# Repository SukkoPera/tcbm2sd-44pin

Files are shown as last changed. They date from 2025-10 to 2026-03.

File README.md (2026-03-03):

# TCBM2SD 44-pin
TCBM2SD is a CBM 1551 paddle replacement and/or mass storage device using an SD card interfacing with the Commodore C16/116/Plus4 simulating a TCBM bus 1551 disk drive.

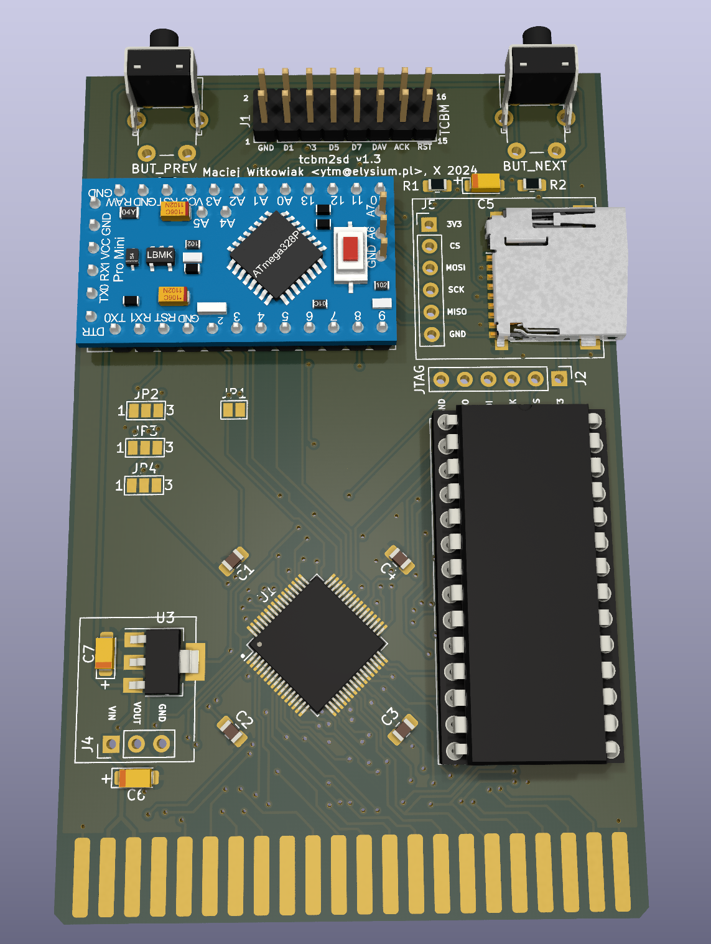
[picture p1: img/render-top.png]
Board


## Summary
This is a 44-pin variant of [the original project by Maciej 'YTM/Elysium' Witkowiak](https://github.com/ytmytm/plus4-tcbm2sd).

This version is still aimed at the C16/C116/Plus4 and it **requires** the usage of a [Plus4MultiExpander](https://github.com/SukkoPera/Plus4MultiExpander) or something similar. It is NOT compatible with the C64/C128.

Isn't Open Hardware great?

## Usage
This variant of the board requires the FPGA to be flashed with the JED file from this project. The corresponding sources are available in the [hdl](hdl/) directory.

Apart from that, please refer to [the original project](https://github.com/ytmytm/plus4-tcbm2sd) for documentation, instructions, etc.

## Releases
If you want to get this board produced, you are recommended to get [the latest release](https://github.com/SukkoPera/tcbm2sd-44pin/releases) rather than the current git version, as the latter might be under development and is not guaranteed to be working.

Every release is accompanied by its Bill Of Materials (BOM) file and any relevant notes about it, which you are recommended to read carefully.

## License
TCBM2SD is licensed under the [Creative Commons Attribution-ShareAlike 4.0 International License](https://creativecommons.org/licenses/by-sa/4.0/).

This documentation is distributed *as is* and WITHOUT ANY EXPRESS OR IMPLIED WARRANTIES whatsoever with respect to its functionality, operability or use, including, without limitation, any implied warranties OF MERCHANTABILITY, SATISFACTORY QUALITY, FITNESS FOR A PARTICULAR PURPOSE or infringement. We expressly disclaim any liability whatsoever for any direct, indirect, consequential, incidental or special damages, including, without limitation, lost revenues, lost profits, losses resulting from business interruption or loss of data, regardless of the form of action or legal theory under which the liability may be asserted, even if advised of the possibility or likelihood of such damages.

## Thanks
- Thanks to Maciej for his amazing work and support.
- 3D model of Arduino Pro Micro by [Toby](https://grabcad.com/library/arduino-pro-mini-5v-16mhz-1).

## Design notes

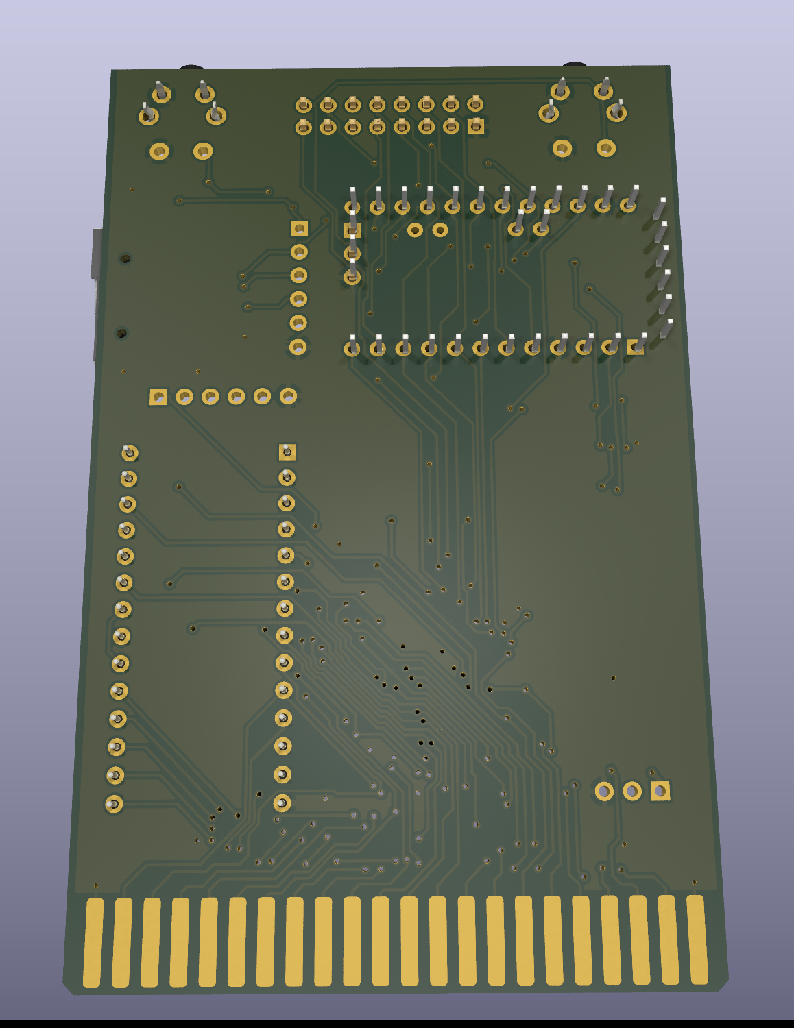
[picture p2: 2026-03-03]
img/render-bottom.png

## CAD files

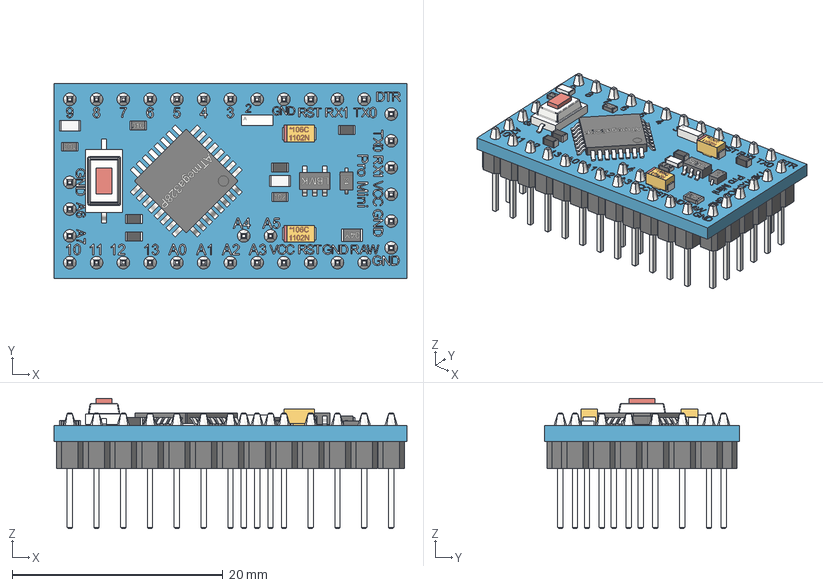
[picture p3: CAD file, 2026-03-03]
tcbm2sd/3dModels/Arduino_Pro_Mini_5V_16MHz.step
33.5 x 18.5 x 12.4 mm
board
led
102_smd_resistor
reset_button
01C_smd_resistor
smd_capacitor
smd_capacitor (1)
ATmega328P
16MHz Resonator v1
led (1)
102_smd_resistor (1)
smd_capacitor (2)
106C_smd_tantalum_capacitor
106C_smd_tantalum_capacitor (2)
5V_regulator
s4_smd_diode
smd_capacitor (3)
04Y_smd_resistor
Pin_Header x 15
Pin_Header (1) x 12
Pin_Header (1) (1) x 6
Pin_Header (2)
Pin_Header (2) (1)
solder x 15
solder (1) x 6
solder (2) x 12
solder (3)
solder (4)

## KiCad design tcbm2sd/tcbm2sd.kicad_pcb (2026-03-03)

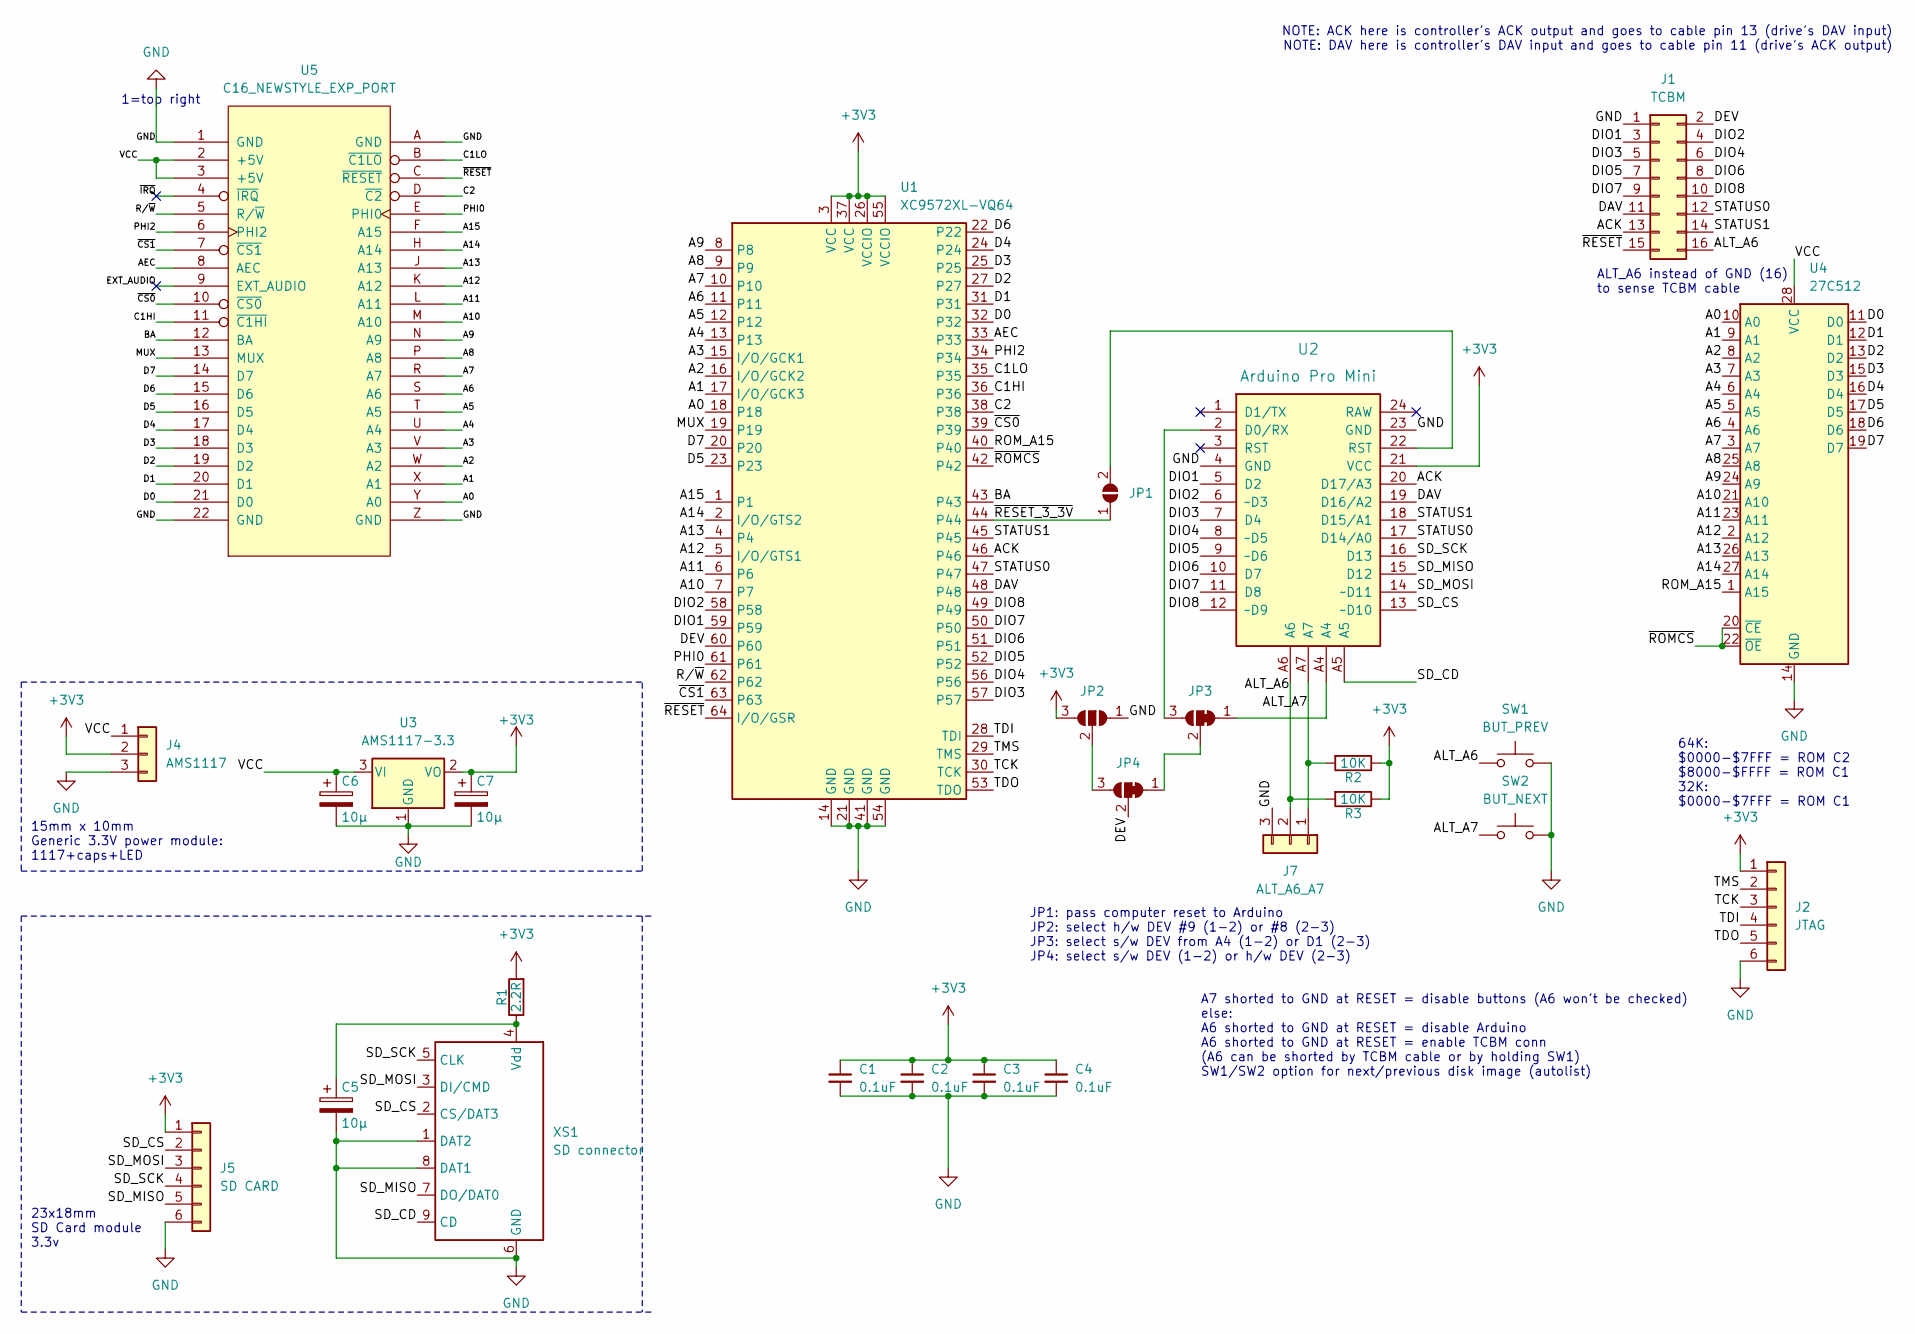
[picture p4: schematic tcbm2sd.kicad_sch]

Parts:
C1, C2, C3, C4: 0.1uF; C_0805_2012Metric_Pad1.18x1.45mm_HandSolder; JLCPCB Part # C49678
C5, C6, C7: 10µ; CP_EIA-3216-12_Kemet-S_Pad1.58x1.35mm_HandSolder; JLCPCB Part # C1969735
J1: TCBM; PinHeader_2x08_P2.54mm_Vertical
J2: JTAG; PinHeader_1x06_P2.54mm_Vertical
J4: AMS1117; PinHeader_1x03_P2.54mm_Vertical
J5: SD CARD; PinHeader_1x06_P2.54mm_Vertical
J7: ALT_A6_A7; PinHeader_1x03_P2.54mm_Vertical
JP1: SolderJumper_2_Open; SolderJumper-2_P1.3mm_Open_Pad1.0x1.5mm
JP2: SolderJumper_3_Open; SolderJumper-3_P1.3mm_Open_Pad1.0x1.5mm_NumberLabels
JP3, JP4: SolderJumper_3_Bridged12; SolderJumper-3_P1.3mm_Bridged12_Pad1.0x1.5mm_NumberLabels
R1: 2.2R; R_0805_2012Metric_Pad1.20x1.40mm_HandSolder; JLCPCB Part # C17521
R2, R3: 10K; R_0805_2012Metric_Pad1.20x1.40mm_HandSolder; JLCPCB Part # C17414
SW1: BUT_PREV; SW_PUSH_6mm_OR_SW_Tactile_SPST_Angled_PTS645Vx58-2LFS
SW2: BUT_NEXT; SW_PUSH_6mm_OR_SW_Tactile_SPST_Angled_PTS645Vx58-2LFS
U1: XC9572XL-VQ64; TQFP-64_10x10mm_P0.5mm; JLCPCB Part # C90569
U2: Arduino Pro Mini; Arduino_Pro_Mini
U3: AMS1117-3.3; SOT-223-3_TabPin2; JLCPCB Part # C6186
U4: 27C512; DIP-28_W15.24mm_Socket
U5: C16_NEWSTYLE_EXP_PORT; EdgeConn-44pin
XS1: SD connector; Conn_uSDcard; JLCPCB Part # C7529389

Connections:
+3V3: C1.1, C2.1, C3.1, C4.1, C7.1, J2.1, J4.2, J5.1, JP2.3 (B), R1.2, R2.1, R3.1, U1.3 (VCC), U1.26 (VCCIO), U1.37 (VCC), U1.55 (VCCIO), U2.21 (VCC), U3.2 (VO)
/A0: U1.18, U4.10 (A0), U5.Y (A0)
/A1: U1.17 (I/O/GCK3), U4.9 (A1), U5.X (A1)
/A2: U1.16 (I/O/GCK2), U4.8 (A2), U5.W (A2)
/A3: U1.15 (I/O/GCK1), U4.7 (A3), U5.V (A3)
/A4: U1.13, U4.6 (A4), U5.U (A4)
/A5: U1.12, U4.5 (A5), U5.T (A5)
/A6: U1.11, U4.4 (A6), U5.S (A6)
/A7: U1.10, U4.3 (A7), U5.R (A7)
/A8: U1.9, U4.25 (A8), U5.P (A8)
/A9: U1.8, U4.24 (A9), U5.N (A9)
/A10: U1.7, U4.21 (A10), U5.M (A10)
/A11: U1.6, U4.23 (A11), U5.L (A11)
/A12: U1.5 (I/O/GTS1), U4.2 (A12), U5.K (A12)
/A13: U1.4, U4.26 (A13), U5.J (A13)
/A14: U1.2 (I/O/GTS2), U4.27 (A14), U5.H (A14)
/A15: U1.1, U5.F (A15)
/ACK: J1.13, U1.46, U2.20 (D17/A3)
/AEC: U1.33, U5.8 (AEC)
/ALT_A6: J1.16, J7.2, R3.2, SW1.1, U2.A6
/ALT_A7: J7.1, R2.2, SW2.1, U2.A7
/BA: U1.43, U5.12 (BA)
/C1HI: U1.36, U5.11 (~C1HI)
/C1LO: U1.35, U5.B (~C1LO)
/C2: U1.38, U5.D (~C2)
/D0: U1.32, U4.11 (D0), U5.21 (D0)
/D1: U1.31, U4.12 (D1), U5.20 (D1)
/D2: U1.27, U4.13 (D2), U5.19 (D2)
/D3: U1.25, U4.15 (D3), U5.18 (D3)
/D4: U1.24, U4.16 (D4), U5.17 (D4)
/D5: U1.23, U4.17 (D5), U5.16 (D5)
/D6: U1.22, U4.18 (D6), U5.15 (D6)
/D7: U1.20, U4.19 (D7), U5.14 (D7)
/DAV: J1.11, U1.48, U2.19 (D16/A2)
/DEV: J1.2, JP4.2 (C), U1.60
/DIO1: J1.3, U1.59, U2.5 (D2)
/DIO2: J1.4, U1.58, U2.6 (~D3)
/DIO3: J1.5, U1.57, U2.7 (D4)
/DIO4: J1.6, U1.56, U2.8 (~D5)
/DIO5: J1.7, U1.52, U2.9 (~D6)
/DIO6: J1.8, U1.51, U2.10 (D7)
/DIO7: J1.9, U1.50, U2.11 (D8)
/DIO8: J1.10, U1.49, U2.12 (~D9)
/EXT_AUDIO: U5.9 (EXT_AUDIO)
/MUX: U1.19, U5.13 (MUX)
/PHI0: U1.61, U5.E (PHI0)
/PHI2: U1.34, U5.6 (PHI2)
/ROM_A15: U1.40, U4.1 (A15)
/R/~W: U1.62, U5.5 (R/~W)
/SD_CD: U2.A5, XS1.9 (CD)
/SD_CS: J5.2, U2.13 (~D10), XS1.2 (CS/DAT3)
/SD_MISO: J5.5, U2.15 (D12), XS1.7 (DO/DAT0)
/SD_MOSI: J5.3, U2.14 (~D11), XS1.3 (DI/CMD)
/SD_SCK: J5.4, U2.16 (D13), XS1.5 (CLK)
/STATUS0: J1.12, U1.47, U2.17 (D14/A0)
/STATUS1: J1.14, U1.45, U2.18 (D15/A1)
/TCK: J2.3, U1.30 (TCK)
/TDI: J2.4, U1.28 (TDI)
/TDO: J2.5, U1.53 (TDO)
/TMS: J2.2, U1.29 (TMS)
/VCC: C6.1, J4.1, U3.3 (VI), U4.28 (VCC), U5.2 (+5V), U5.3 (+5V)
/~CS0: U1.39, U5.10 (~CS0)
/~CS1: U1.63, U5.7 (~CS1)
/~IRQ: U5.4 (~IRQ)
/~RESET_3_3V: JP1.1 (A), U1.44
/~RESET: J1.15, U1.64 (I/O/GSR), U5.C (~RESET)
/~ROMCS: U1.42, U4.20 (~CE), U4.22 (~OE)
GND: C1.2, C2.2, C3.2, C4.2, C5.2, C6.2, C7.2, J1.1, J2.6, J4.3, J5.6, J7.3, JP2.1 (A), SW1.2, SW2.2, U1.14 (GND), U1.21 (GND), U1.41 (GND), U1.54 (GND), U2.4 (GND), U2.23 (GND), U3.1 (GND), U4.14 (GND), U5.1 (GND), U5.22 (GND), U5.A (GND), U5.Z (GND), XS1.1 (DAT2), XS1.6 (GND), XS1.8 (DAT1)
unnamed: JP1.2 (B), U2.22 (RST)
unnamed: JP2.2 (C), JP4.3 (B)
unnamed: JP3.1 (A), U2.A4
unnamed: JP3.3 (B), U2.2 (D0/RX)
unnamed: JP3.2 (C), JP4.1 (A)
unnamed: C5.1, R1.1, XS1.4 (Vdd)

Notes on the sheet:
ALT_A6 instead of GND (16) to sense TCBM cable
15mm x 10mm Generic 3.3V power module: 1117+caps+LED
JP1: pass computer reset to Arduino JP2: select h/w DEV #9 (1-2) or #8 (2-3) JP3: select s/w DEV from A4 (1-2) or D1 (2-3) JP4: select s/w DEV (1-2) or h/w DEV (2-3)
A7 shorted to GND at RESET = disable buttons (A6 won't be checked) else: A6 shorted to GND at RESET = disable Arduino A6 shorted to GND at RESET = enable TCBM conn (A6 can be shorted by TCBM cable or by holding SW1) SW1/SW2 option for next/previous disk image (autolist)
NOTE: ACK here is controller's ACK output and goes to cable pin 13 (drive's DAV input) NOTE: DAV here is controller's DAV input and goes to cable pin 11 (drive's ACK output)
1=top right
23x18mm SD Card module 3.3v
64K: $0000-$7FFF = ROM C2 $8000-$FFFF = ROM C1 32K: $0000-$7FFF = ROM C1

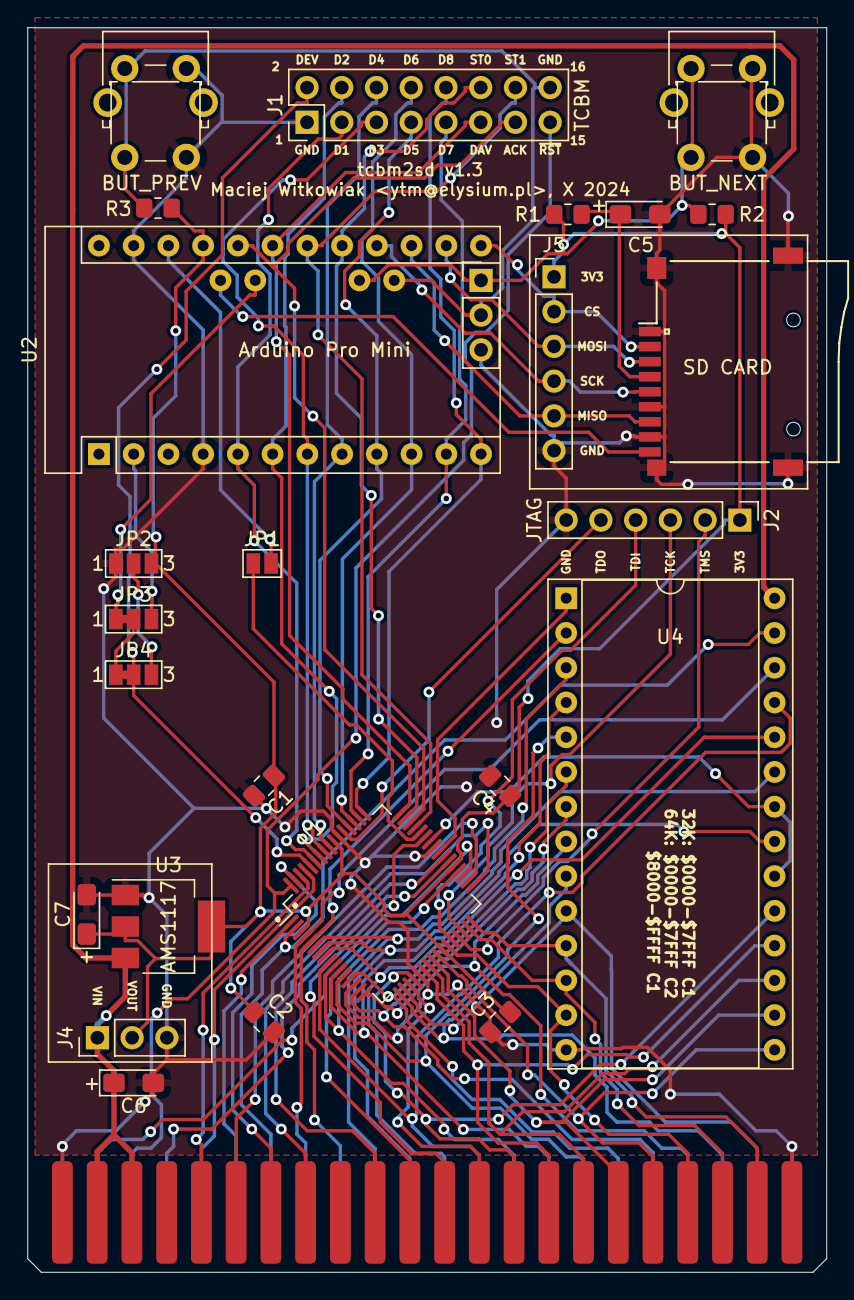
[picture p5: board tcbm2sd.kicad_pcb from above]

Board: 2 copper layers, 58.4 x 91.0 mm, 27 parts (0 on the bottom side), 72 nets.

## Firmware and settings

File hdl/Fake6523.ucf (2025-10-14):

# Fake6523A-28
NET "_reset"		LOC = "P64"  ; # /RESET exp. C
NET "_write"		LOC = "P62"  ; # R/W exp. 5
NET "data<0>"		LOC = "P32"  ; # D0 exp. 21
NET "data<1>"		LOC = "P31"  ; # D1 exp. 20
NET "data<2>"		LOC = "P27"  ; # D2 exp. 19
NET "data<3>"		LOC = "P25"  ; # D3 exp. 18
NET "data<4>"		LOC = "P24"  ; # D4 exp. 17
NET "data<5>"		LOC = "P23"  ; # D5 exp. 16
NET "data<6>"		LOC = "P22"  ; # D6 exp. 15
NET "data<7>"		LOC = "P20"  ; # D7 exp. 14
NET "port_a<0>"	LOC = "P59"  ; # DIO1, <-> wire 3
NET "port_a<1>"	LOC = "P58"  ; # DIO2, <-> wire 4
NET "port_a<2>"	LOC = "P57"  ; # DIO3, <-> wire 5
NET "port_a<3>"	LOC = "P56"  ; # DIO4, <-> wire 6
NET "port_a<4>"	LOC = "P52"  ; # DIO5, <-> wire 7
NET "port_a<5>"	LOC = "P51"  ; # DIO6, <-> wire 8
NET "port_a<6>"	LOC = "P50"  ; # DIO7, <-> wire 9
NET "port_a<7>"	LOC = "P49"  ; # DIO8, <-> wire 10
NET "port_b<0>"	LOC = "P47"  ; # STATUS0, <-, wire 12
NET "port_b<1>"	LOC = "P45"  ; # STATUS1, <-, wire 14
NET "port_c<6>"	LOC = "P46"  ; # ACK, ->, wire 13 (controller's ACK out, drive's DAV in)
NET "port_c<7>"	LOC = "P48"  ; # DAV, <-, wire 11 (controller's DAV in,  drive's ACK out)
NET "rs<0>"			LOC = "P18"  ; # A0 exp. Y
NET "rs<1>"			LOC = "P17"  ; # A1 exp. X
NET "rs<2>"			LOC = "P16"  ; # A2 exp. W

# other inputs
NET "phi2"			LOC = "P34"  ;	# Phi2 exp. 24
NET "aec" 			LOC = "P33"  ; # AEC exp. 22
NET "ba"				LOC = "P43"  ; # BA exp. 13

# ROM control
NET "c1lo"			LOC = "P35"	 ; # J3-1			<- C1LO exp. B
NET "c1hi"			LOC = "P36"  ; # J3-2			<- C1HI exp. 6
NET "c2"				LOC = "P38"  ; # J3-3			<- C2  exp. D (combined C2LO/C2HI)
NET "cs0"			LOC = "P39"  ; # J3-4			<- CS0 exp. 10
NET "rom_a15"		LOC = "P40"  ; # J3-5			-> ROM A15 1
NET "rom_cs"		LOC = "P42"  ; # /CAS			-> ROM /CE/OE 20+22

# PLA inputs
NET "pla_i<1>"		LOC = "P6"	 ; # PLA I1 (8)   <- A11 exp. L
NET "pla_i<2>"		LOC = "P5"	 ; # PLA I2 (7)   <- A12 exp. K
NET "pla_i<3>"    LOC = "P4"	 ; # PLA I3 (6)   <- A13 exp. J
NET "pla_i<4>"		LOC = "P2"	 ; # PLA I4 (5)   <- A14 exp. H
NET "pla_i<5>"		LOC = "P1"	 ; # PLA I5 (4)   <- A15 exp. F
NET "pla_i<6>"		LOC = "P61"  ; # PLA I6 (3)   <- Phi0 exp. E
NET "cs1"			LOC = "P63"	 ; #                 /CS1 exp. 7
NET "pla_i<8>"		LOC = "P60"  ; # PLA I8 (27)  <- DEV signal from device (0 or 1), wire 2
NET "pla_i<9>"    LOC = "P7"   ; # PLA I9 (26)  <- A10 exp. M
NET "pla_i<10>"   LOC = "P19"  ; # PLA I10 (25) <- MUX exp. 12
NET "pla_i<11>"   LOC = "P8"   ; # PLA I11 (24) <- A9 exp. N
NET "pla_i<12>"   LOC = "P9"   ; # PLA I12 (23) <- A8 exp. P
NET "pla_i<13>"   LOC = "P10"  ; # PLA I13 (22) <- A7 exp. R
NET "pla_i<14>"   LOC = "P11"  ; # PLA I14 (21) <- A6 exp. S
NET "pla_i<15>"   LOC = "P12"  ; # PLA I15 (20) <- A5 exp. T
# additional inputs
NET "addr<4>"     LOC = "P13"  ; # PLA xxx      <- A4 exp. U
NET "addr<3>"     LOC = "P15"  ; # PLA xxx      <- A3 exp. V
# additional output (temp. disabled)
NET "_resetout"   LOC = "P44"  ; # copy 5V /RESET to 3.3V /RESET

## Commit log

2025-08-19 Switch to 44-pin connector
    [tcbm2sd.kicad_pcb, tcbm2sd.kicad_sch]
2025-10-14 Remove all files that should be taken from upstream
    [drv1551.cfg, geosboot.cfg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]
2025-10-14 Update HDL files for 44-pin changes Namely: - Pin 38 = /C2 (new signal) - Pin 39 = /CS0 - Pin 63 = /CS1 - /C2LO = /C2 or /CS0 - /C2HI = /C2 or /CS1
2026-03-03 Fix 3D model
    [Arduino_Pro_Mini_5V_16MHz.step, tcbm2sd.kicad_pcb]
